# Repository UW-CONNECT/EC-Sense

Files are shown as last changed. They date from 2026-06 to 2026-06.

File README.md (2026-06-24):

# EC-Sense: Radio Energy Capture for Wireless Soil Moisture Sensing

<b>Abstract</b> : Understanding the spatial and temporal variations in soil moisture is critical for sustainable agriculture. Contactless
approaches such as ground penetrating radar, and satellite are either expensive or offer limited resolution, making them
less scalable. In-situ sensors, while offering high resolution, often involve challenging data retrieval processes. In this
work, we propose EC-Sense, a wire-free system for in-situ soil moisture sensing that employs ultra-low-power sensor
Tags buried underground and reference Tags placed on the surface. EC-Sense introduces a novel sensing modality
based on the energy capture time (EC Time). We define EC Time as the time taken by a sensor Tag to harvest sufficient
energy to activate a response; EC Time serves as a proxy for path loss in soil, which is a clear indicator of soil moisture.
Our approach of using differential path loss, estimated from the EC Times of both surface and buried Tags, isolates
soil-induced pathloss from that of the environment above ground. By decoupling sensing from communication, EC-Sense
overcomes the challenges present in existing RF-based soil sensors that rely on wide-band sensing. Despite using an
active radio, we estimate an impressive battery life of over 16 years for the sensor Tags. We deployed EC-Sense in an
open agriculture field and measured soil moisture at multiple depths over multiple days. We show experimentally that
EC-Sense can measure moisture at depths of 40cm with 98% accuracy compared to ground truth

The figure below shows the EC-Sense framework :

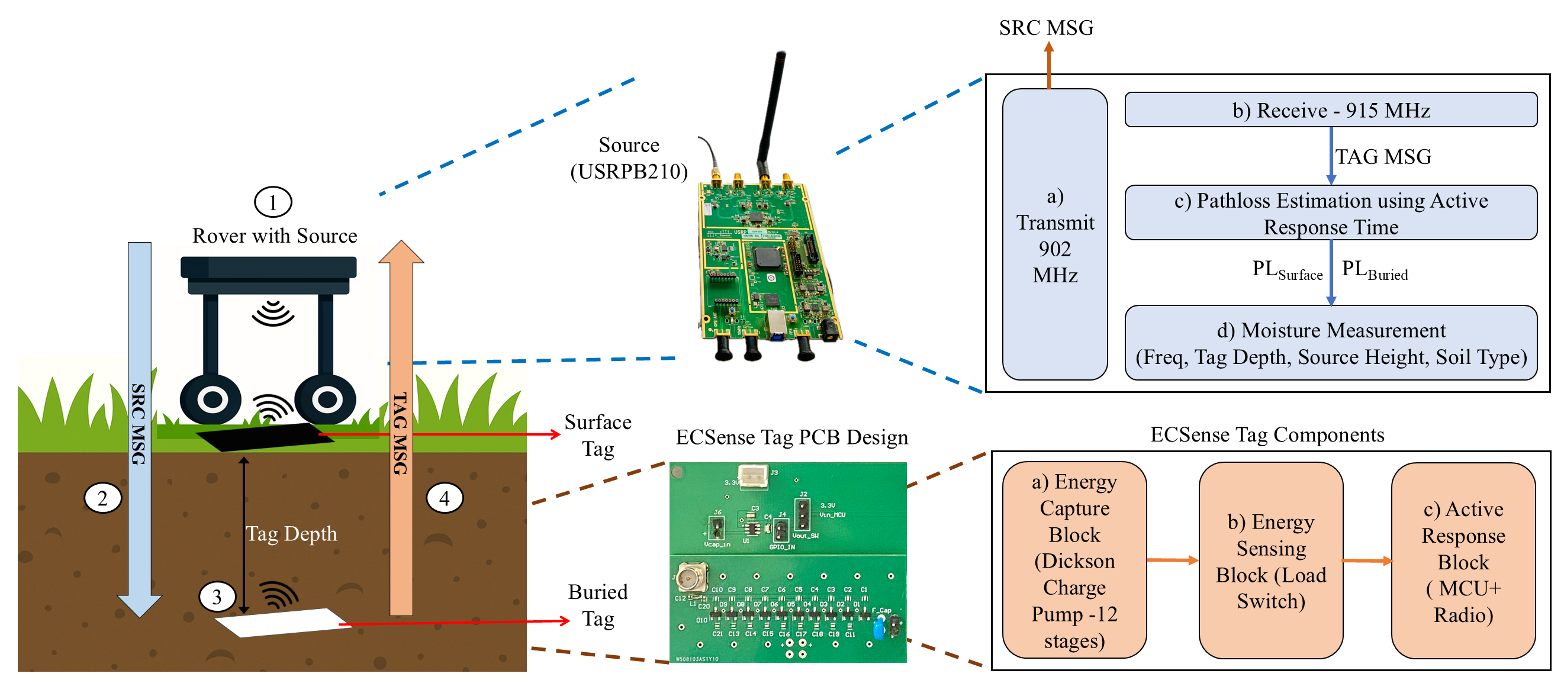
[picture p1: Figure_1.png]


## Hardware and Software
* Sotware codes for Source can be found in [Source](Source/) folder.
* The PCB design of Tag can be found in [Tag Hardware](Tag/Hardware_Design) folder.
* Software codes for Tag can be found in [Tag Software](Tag/Software_Codes) folder.

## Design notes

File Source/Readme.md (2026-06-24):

File USRP_Transmit_Packet_Detection.py is used to transmit and receive simulateously at different frequencies. This code is written in Python using threads.

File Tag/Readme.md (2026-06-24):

This section has necessary resources for re-creating EC-Sense Tag. The Tag hardware design including PCB files can be found in Tag Hardware folder.

TAG COST : We use off-the shelf components in our Tag design thereby reducing the overall cost. Diodes for the EC block would cost around $12 for 12-stage board with 24 diodes. The total cost of capacitors and inductors is around \$3. The energy sensing block cost about $12. Finally, the cost of microcontroller and radio chip is around $3. 915MHz whip antennas cost about $6, however the cost depends on gain and the frequency range.
The total cost of our Tag excluding antennas comes to \$30. The cost of the Tag can be lower if ordered in bulk quantities.

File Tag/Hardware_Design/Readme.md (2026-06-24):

The PCB design for the Tag are in the folder. Tag PCB was done in Altium Software. Below is the picture of Tag PCB schematic and Circuit schematic.

<b>PCB Schematic</b>

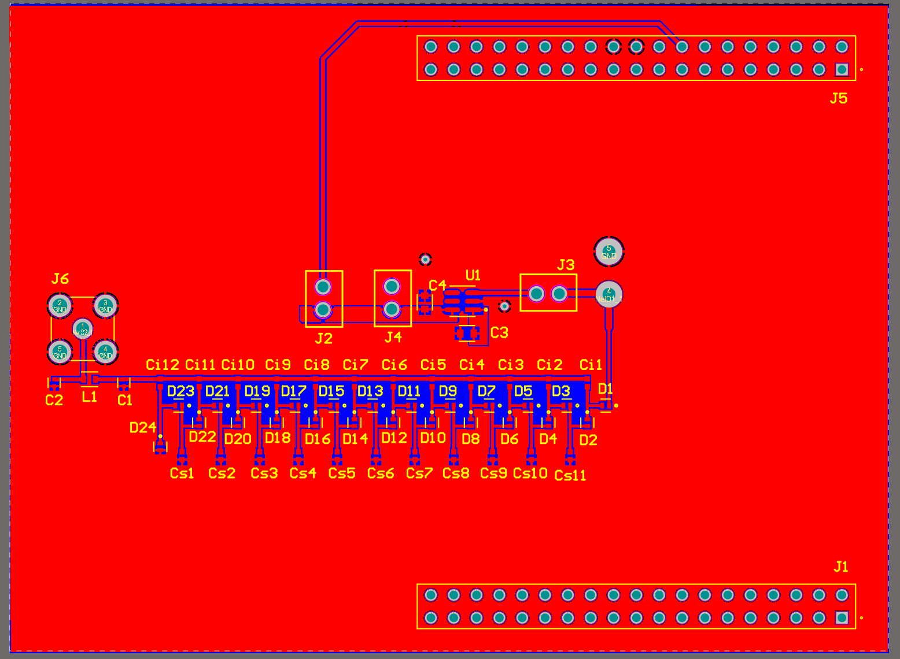
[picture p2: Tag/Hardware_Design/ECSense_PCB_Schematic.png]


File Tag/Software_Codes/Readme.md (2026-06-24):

The Code for packet detection and moisture estimation is written in MATLAB. Autocorrelation fuction detects and demodulates the packet. Calaculate_Pathloss_1 function takes the time as input and output corresponding incident power and pathloss. Calculate_VWC_from_Pathlosses function takes in pathloss values as input and gives outputs the measured moisture value.

All the function required for moisture estimation are uploaded in this folder. Run Packet_Detection_Moisture_Estimation code.

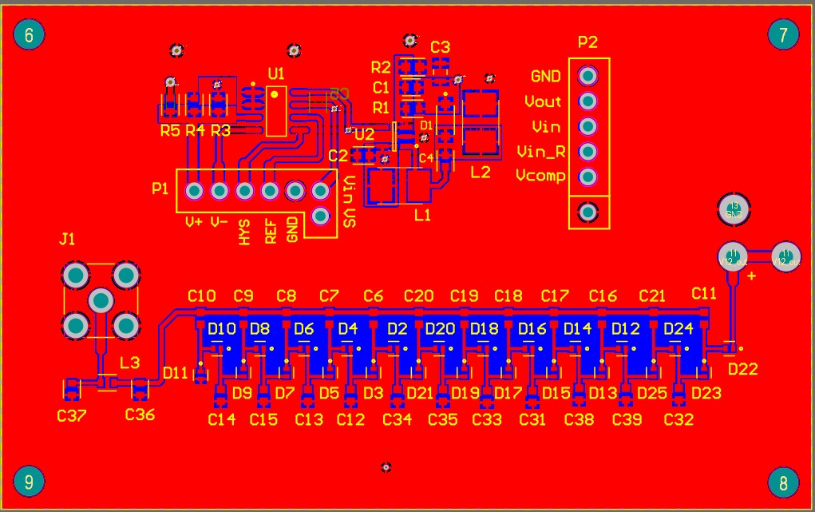
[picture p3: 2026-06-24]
Tag/Hardware_Design/PCB_Schematic.jpg

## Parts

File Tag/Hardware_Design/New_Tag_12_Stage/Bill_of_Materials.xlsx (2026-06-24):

Name | Description | Designator | Quantity | Product Link
C0603C479C3GACAUTO | CAP CER 4.7PF 25V C0G/NP0 0603 | C1 | 1 | https://www.digikey.com/en/products/detail/kemet/C0603C479C3GACAUTO/3314896
GRM188R61E475KE11D | CAP CER 4.7UF 25V X5R 0603 | C2 | 1 | https://www.digikey.com/en/products/detail/murata-electronics/GRM188R61E475KE11D/3900465
GRM21BR61C106KE15K | CAP CER 10UF 16V X5R 0805 | C3 | 1 | https://www.digikey.com/en/products/detail/murata-electronics/GRM21BR61C106KE15K/2546903
EMK107B7105KA-T | CAP CER 1UF 16V X7R 0603 | C4, C5 | 2 | https://www.digikey.com/en/products/detail/taiyo-yuden/EMK107B7105KA-T/930593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
VJ0603A470FXACW1BC | CAP CER 47PF 50V C0G/NP0 0603 | C6, C7, C8, C9, C10, C12, C13, C14, C15, C16, C17, C18, C19, C20, C31, C32, C33, C34, C35 | 19 | https://www.digikey.com/en/products/detail/vishay-vitramon/VJ0603A470FXACW1BC/8304234
GRT31CR61H106KE01L | CAP CER 10UF 50V X5R 1206 | C11, C21, C22, C23, C24, C25, C26, C27, C28, C29, C30 | 11 | https://www.digikey.com/en/products/detail/murata-electronics/GRT31CR61H106KE01L/5416878
CBR06C109B5GAC | CAP CER 1PF 50V C0G/NP0 0603 | C36 | 1 | https://www.digikey.com/en/products/detail/kemet/CBR06C109B5GAC/3473694
CBR06C159B5GAC | CAP CER 1.5PF 50V C0G/NP0 0603 | C37 | 1 | https://www.digikey.com/en/products/detail/kemet/CBR06C159B5GAC/3473737
MBR0520L-TP | DIODE SCHOTTKY 20V 500MA SOD123 | D1 | 1 | https://www.digikey.com/en/products/detail/micro-commercial-co/mbr0520l-tp/3191585
SMS7630-040LF | RF DIODE SCHOTTKY 1V 250MW 0402 | D2, D3, D4, D5, D6, D7, D8, D9, D10, D11, D12, D13, D14, D15, D16, D17, D18, D19, D20, D21 | 20 | https://www.digikey.com/en/products/detail/skyworks-solutions-inc/sms7630-040lf/2349593
CONREVSMA001 | CONN RP-SMA RCPT STR 50 OHM PCB | J1 | 1 | https://www.digikey.com/en/products/detail/te-connectivity-linx/CONREVSMA001/340144
LQH43CN100K03L | FIXED IND 10UH 650MA 240MOHM SMD | L1, L2 | 2 | https://www.digikey.com/en/products/detail/murata-electronics/LQH43CN100K03L/599911
0603DC-6N8XJRW | FIXED IND 6.8NH 2.58A 48MOHM SMD | L3 | 1 | https://www.digikey.com/en/products/detail/coilcraft/0603dc-6n8xjrw/12714771
LJQ-ZP-40P-DPZ-2.54-10 | 40 pin x 10pcs Male Headers Pins Straight Single Row Gold Plated Pitch 2.54mm | P1,P2,P3,P4,Vout,MCU_VDD | 1 | https://www.amazon.com/Straight-Breakaway-Connector-Breadboard-Electronic/dp/B09MYBRW3F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
MK-197 | Qunqi 60Pcs 40 Pin 2.54mm Single Row Straight Female PCB Header Connector Strip | P5, P6 | 1 | https://www.amazon.com/Qunqi-2-54mm-Straight-Connector-Arduino/dp/B07CGGSDWF
ERJ-3EKF1004V | RES SMD 1M OHM 1% 1/10W 0603 | R1, R3, R4 | 3 | https://www.digikey.com/en/products/detail/panasonic-electronic-components/ERJ-3EKF1004V/196033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
RMCF0603FT604K | RES 604K OHM 1% 1/10W 0603 | R2 | 1 | https://www.digikey.com/en/products/detail/stackpole-electronics-inc/RMCF0603FT604K/1714165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
LTC1540IS8#PBF | IC COMPARATOR 1 W/VOLT REF 8SO | U1 | 1 | https://www.digikey.com/en/products/detail/analog-devices-inc/LTC1540IS8-PBF/889348
LT1615ES5#TRPBF | IC REG BST SEPIC ADJ 0.3A TSOT23 | U2 | 1 | https://www.digikey.com/en/products/detail/analog-devices-inc/LT1615ES5-TRPBF/960068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
